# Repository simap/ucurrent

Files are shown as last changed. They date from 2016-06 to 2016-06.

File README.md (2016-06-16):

µCurrent
------------------

Based entirely on [µCurrent by David Jones at EEVBlog](https://www.eevblog.com/projects/ucurrent/). 

µCurrent allows accurate measurement of micro and nano amps with a low burden voltage by outputting one millivolt per micro/nano amp. See the link above for all kinds of awesome if you want to know more.

This is a slightly simplified variation on µCurrent that allows for measuring micro and nano amps only. I used DPST switches and remove the milli amp measurement and the battery test (I can just probe the battery). The board is layed out for single sided home PCB manufacuring. I used a few through hole resistors for the non precision components to avoid extra jumpers. 

I've included a 3D printed case as well. Just melt the tabs down once the PCB is in place.

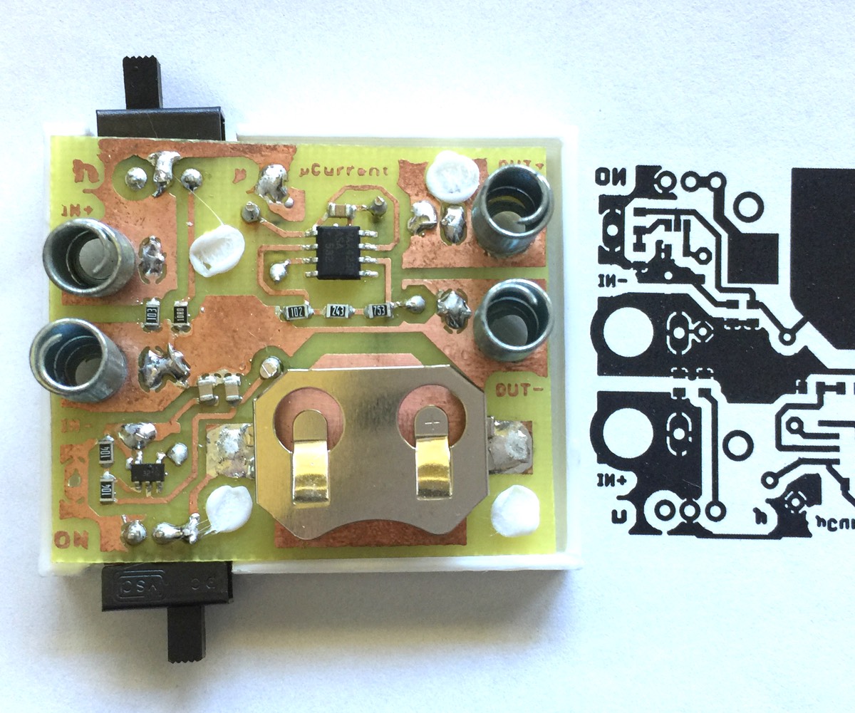
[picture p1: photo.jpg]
Photo w/ case

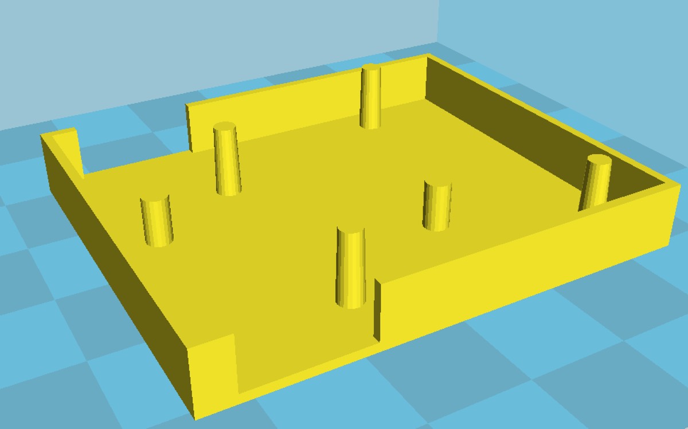
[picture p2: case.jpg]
case 3d

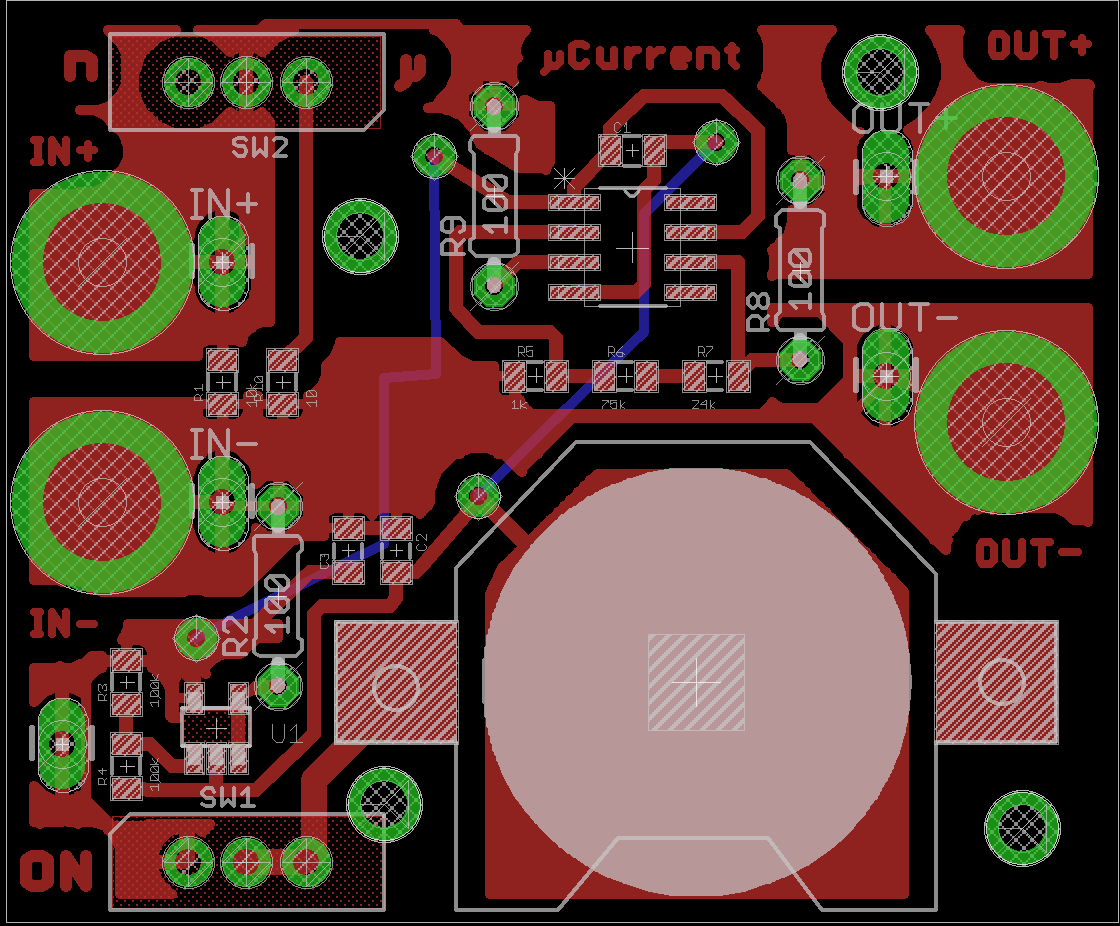
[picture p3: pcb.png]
pcb design


Neat Stuff
----------------

The crazy thing is that you can measure very low current things, for example an LED will generate current! I got about 160na when pointed at an indoor light. My project running on a PIC10LF320 in sleep mode is using only 560na. Cool!

You can also hook this up to a scope for even more sensitive measurements and detail. The amplifier used is very accurate and low noise.

Parts List
--------------

Part | precision | size | qty
---- | ----------| ---  | ----
100R | 5%        | 1/4w | 3
100K | 1%        | 0805 | 2
1K   | 0.1%      | 0805 | 1
75K  | 0.1%      | 0805 | 1
24K  | 0.1%      | 0805 | 1
10K  | 0.1%      | 0805 | 1
10R  | 0.1%      | 0805 | 1
100nF Capacitor|         | 0805 | 3
SPDT Slide Switch|  | PCB .1" | 2
Lithium Battery | | CR2032 |1
SMT Battery holder [mouser part](http://www.mouser.com/ProductDetail/Linx-Technologies/BAT-HLD-001/) | | 20mm| 1
MAX4239ASA+ Opamp|  | SO8 | 1 
LMV321AS5X Opamp |  | SOT23-5 | 1

I used some springs I scavenged from some old RadioShack learn electronics kits instead of banana jacks or binding posts.

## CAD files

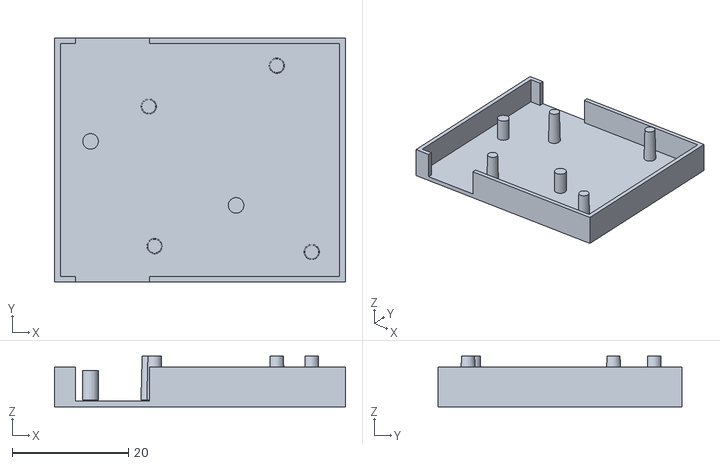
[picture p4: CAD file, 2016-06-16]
case.stl
50.0 x 42.0 x 8.70

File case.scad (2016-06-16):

$fs=.4;

tolerance = 0.2;

t = 1;

boardW = 47 + t;
boardL = 39 + t;
boardH = 6;
switchW = 12.5 + tolerance;
switchH = 5;

plugH = switchH + 2.5;
plugR = 1.35;


union() {
    difference() {
        cube([boardW+t*2,boardL+t*2,boardH+t-tolerance]);
        translate([t,t,t])
        cube([boardW,boardL,boardH]);
        
        translate([10 - switchW/2,36+3,t])
        #cube([switchW,4, boardH]);
        
        translate([10 - switchW/2,-1,t])
        #cube([switchW,4, boardH]);
        
        
        //translate([29 - 22/2,-1,t])
        //#cube([22,4, boardH]);
    }
    
    


}
translate([t + tolerance,t + tolerance,t + tolerance])
union() {    
    translate([15,29])
    cylinder(h=plugH,r1=plugR, r2=plugR-tolerance);
    translate([37,36])
    cylinder(h=plugH,r1=plugR, r2=plugR-tolerance);
    translate([16,5])
    cylinder(h=plugH,r1=plugR, r2=plugR-tolerance);
    translate([43,4])
    cylinder(h=plugH,r1=plugR, r2=plugR-tolerance);
    
    
        //supports
    translate([30,12,0])
    cylinder(h=switchH,r=plugR);
    translate([5,23,0])
    cylinder(h=switchH,r=plugR);
}

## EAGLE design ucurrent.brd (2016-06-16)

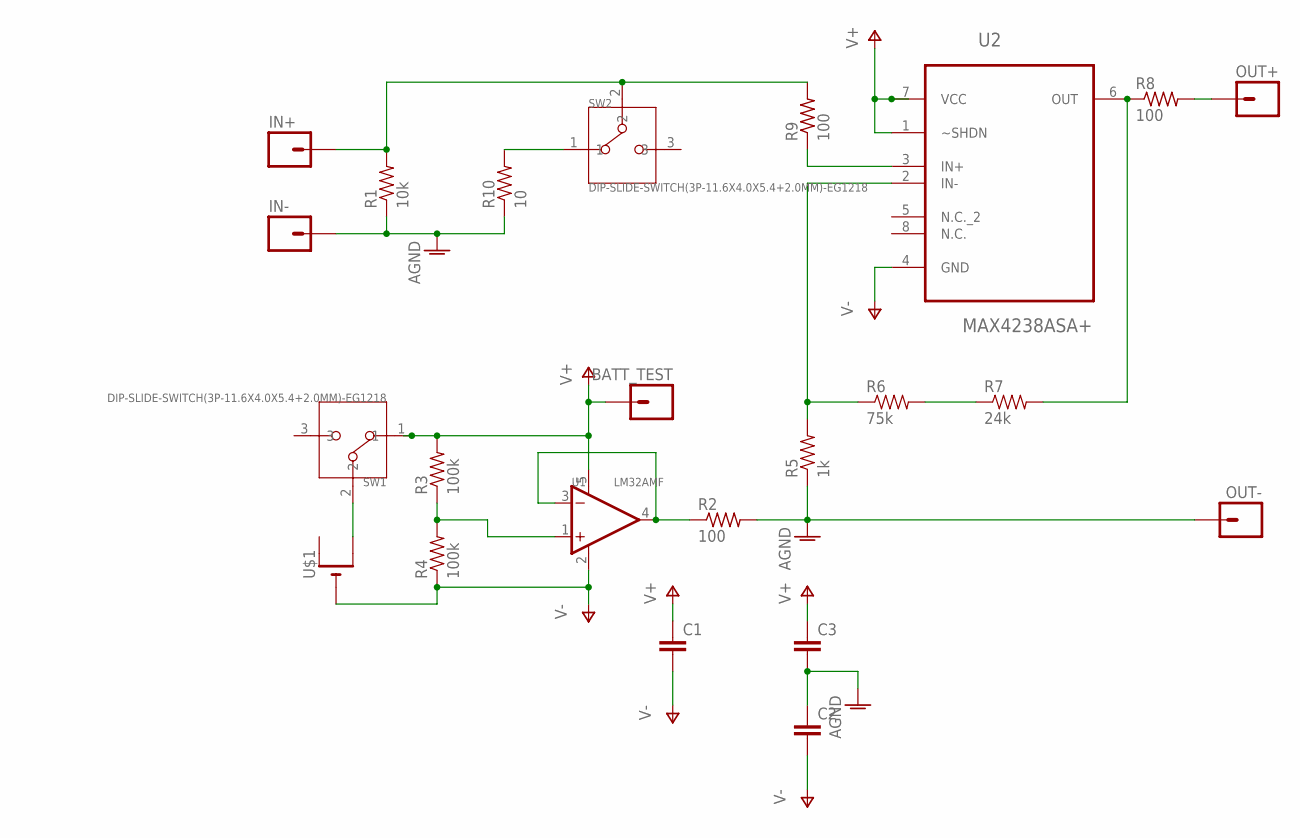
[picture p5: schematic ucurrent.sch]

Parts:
BATT_TEST: M01PTH_LONGPAD; 1X01_LONGPAD
C1, C2, C3: CAP0805; 0805
IN+: M01PTH_LONGPAD; 1X01_LONGPAD
IN-: M01PTH_LONGPAD; 1X01_LONGPAD
OUT+: M01PTH_LONGPAD; 1X01_LONGPAD
OUT-: M01PTH_LONGPAD; 1X01_LONGPAD
R1: 10k; 0805
R2, R8, R9: 100; 0204/7
R3, R4: 100k; 0805
R5: 1k; 0805
R6: 75k; 0805
R7: 24k; 0805
R10: 10; 0805
SW1, SW2: DIP-SLIDE-SWITCH(3P-11.6X4.0X5.4+2.0MM)-EG1218; SW3-2.5-11.6X4.0X5.4+2.0MM
U1: LM32AMF; SOT-23-5
U2: MAX4238ASA+; SOIC127P600X175-8N
U$1: CR2032SMT; CR2032-SMD

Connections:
AGND: C2.1, C3.2, IN-.1, OUT-.1, R1.1, R2.2, R5.1, R10.1
BAT+: SW1.2, U$1.+$2 (+1)
IN+: IN+.1, R1.2, R9.2, SW2.2
unnamed: R3.1, R4.2, U1.1 (IN+)
unnamed: R9.1, U2.3 (IN+)
unnamed: R7.2, R8.1, U2.6 (OUT)
unnamed: R6.2, R7.1
unnamed: R5.2, R6.1, U2.2 (IN-)
unnamed: R2.1, U1.3 (IN-), U1.4 (OUT)
unnamed: R10.2, SW2.1
OUT+: OUT+.1, R8.2
V+: BATT_TEST.1, C1.1, C3.1, R3.2, SW1.1, U1.5 (V+), U2.1 (~SHDN), U2.7 (VCC)
V-: C1.2, C2.2, R4.1, U1.2 (V-), U2.4 (GND), U$1.-

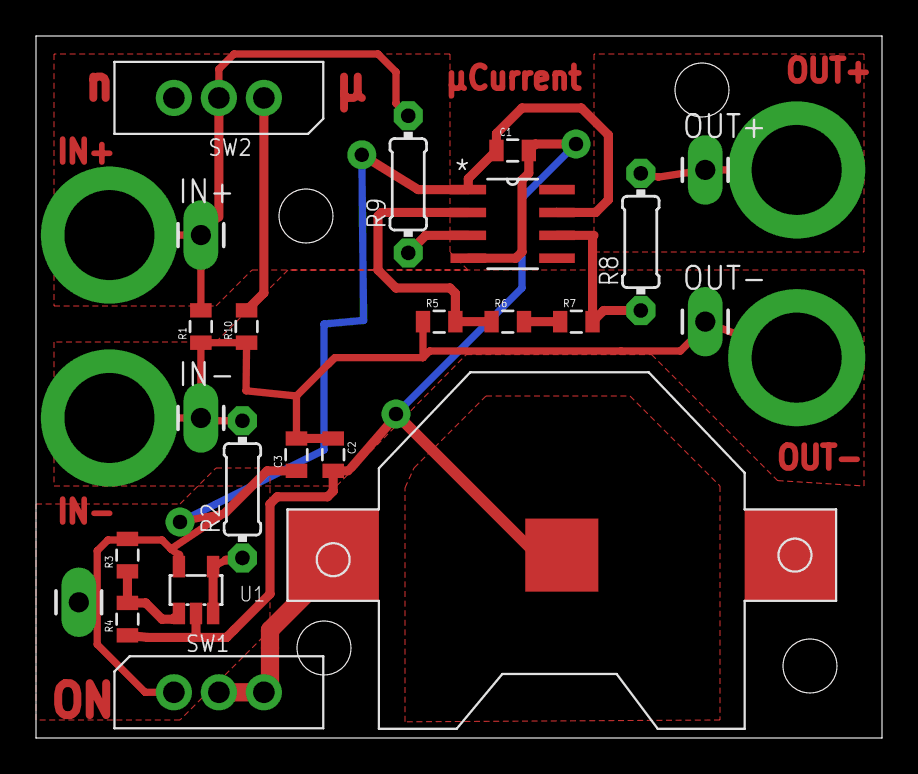
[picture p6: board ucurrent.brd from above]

Board: 2 copper layers, 47.0 x 39.0 mm, 23 parts (0 on the bottom side), 13 nets.

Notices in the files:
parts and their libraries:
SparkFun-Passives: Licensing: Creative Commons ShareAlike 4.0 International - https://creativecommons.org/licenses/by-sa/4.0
